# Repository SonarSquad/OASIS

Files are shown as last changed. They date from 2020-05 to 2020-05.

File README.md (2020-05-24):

# OASIS
Contains the complete code, circuit schematics and designs for the OASIS prototype system.
The full OASIS - A low-cost modular echosounder thesis report should also be red for a better understanding if further development of the system are to be investigated.  

**CONTENT: folder and content**
- LNA_Rev3: PCB design files for the LNA board (ALTIUM).
- Oasis_ADC_PCB: PCB design files and gerbers for the ADC board (KICAD).
- Oasis_MCU_bridge_PCB: PCB design files and gerbers for MCU board (KICAD).
- Python code and drivers: Main python script and C- code drivers for the OASIS system
- MCU_ATmega4809: Code for waveform-generation on the ATmega4809. 
- SPI_test_alternative_ADC: Example code for setting up SPI communication on the Raspberry Pi 4 (not used in OASIS prototype).  

**HARDWARE modules:**
- LNA board - Low noise amplifier. (designed and tested)
- MCU board - ATmega4809 Full-bridge module. (designed and tested)
- ADC board - ADS8422 board Analog to Digital converter. (designed and tested)
- Raspberry pi 4 model B (4GB RAM). (bought and tested)

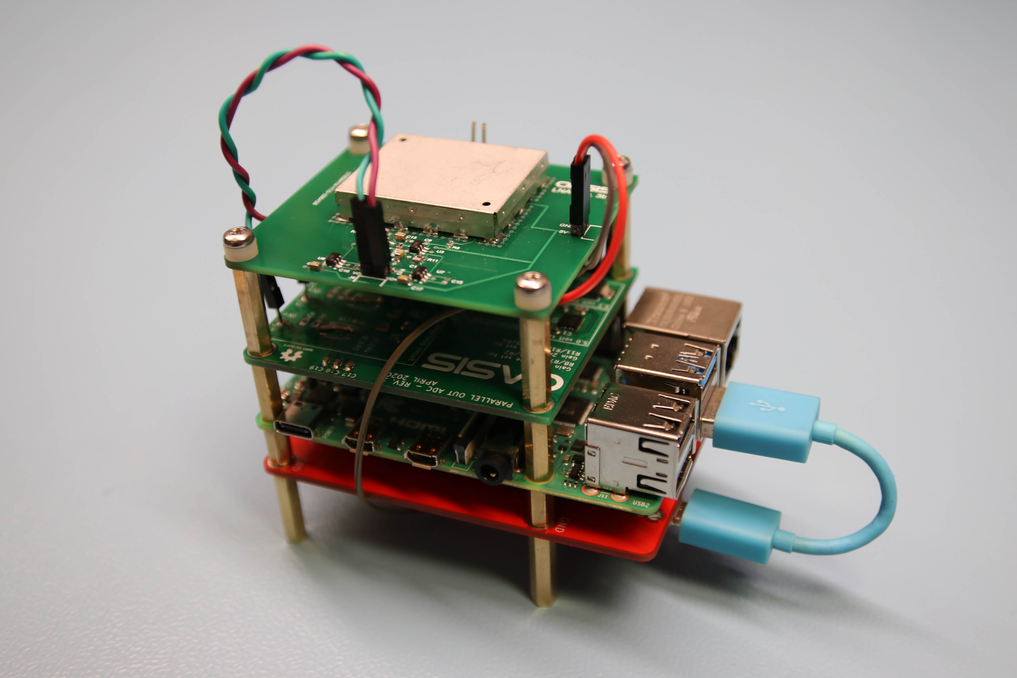
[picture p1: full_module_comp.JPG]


**OASIS Prototype achievements:** 
1. System startup, Transmit a pulse at preset frequency (200kHz).
    - Pulse generaton is done on sepparate microcontroller (MCU).
    
2. Amplify returning echo with LNA.  
    
3. Sample returning echo, (switch not developed yet - two transducers used while testing, one for transmit and one for receive). 
    - Receive and sample incomming returning echo. Sampling @ 1.7 Msps.  

4. Plotting and light processing of received signal.
    - Plot: FFT. 
    - Plot: Time vs. voltage. 
    
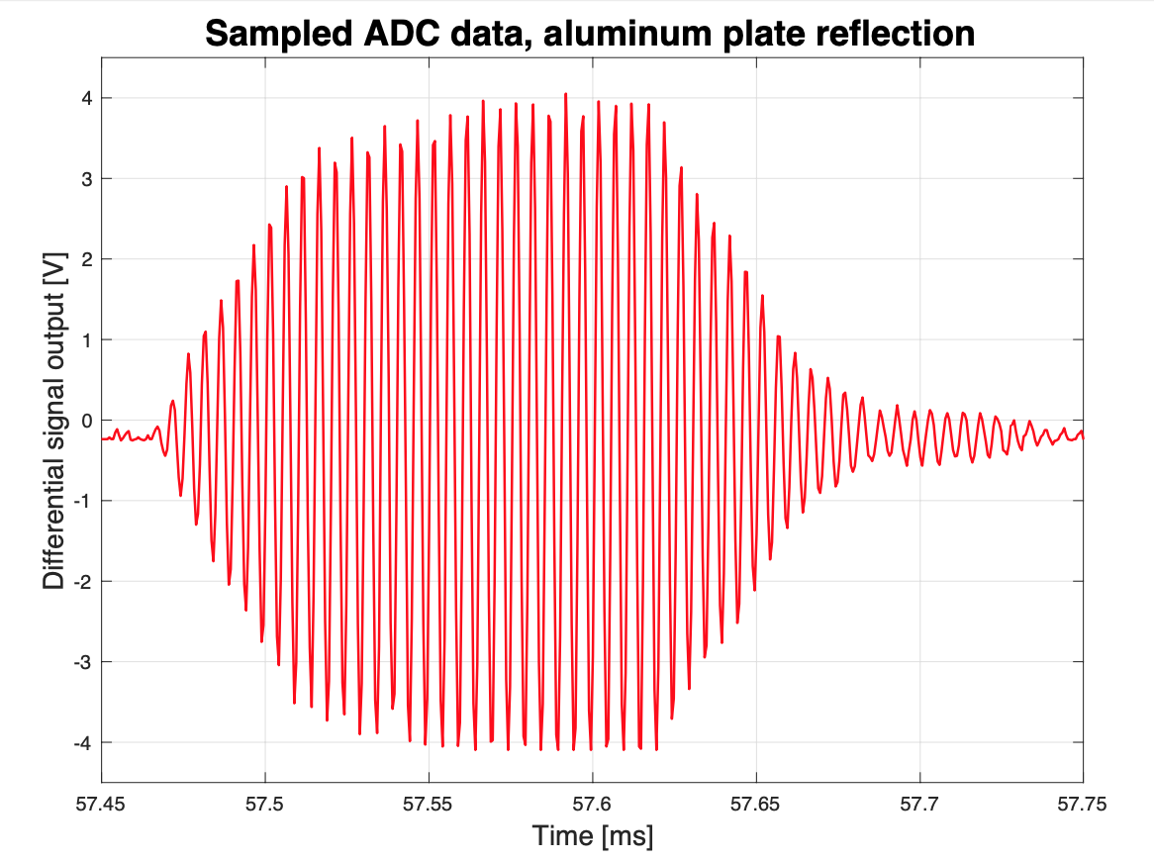
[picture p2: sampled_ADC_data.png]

________________________________________________________________________________________________________
**CONTACT:** 
- Martin Ericsson - tlf: 92649342, email: martincse94@gmail.com 
- Tor K. Gjerde - tlf: 46934462, email: torgjerde.nor@gmail.com
- Torbjørn Willson - tlf: 46810798, email: torbjorw@ntnu.no
- Einar Avdem - tlf: 98813120, email: einarav@stud.ntnu.no

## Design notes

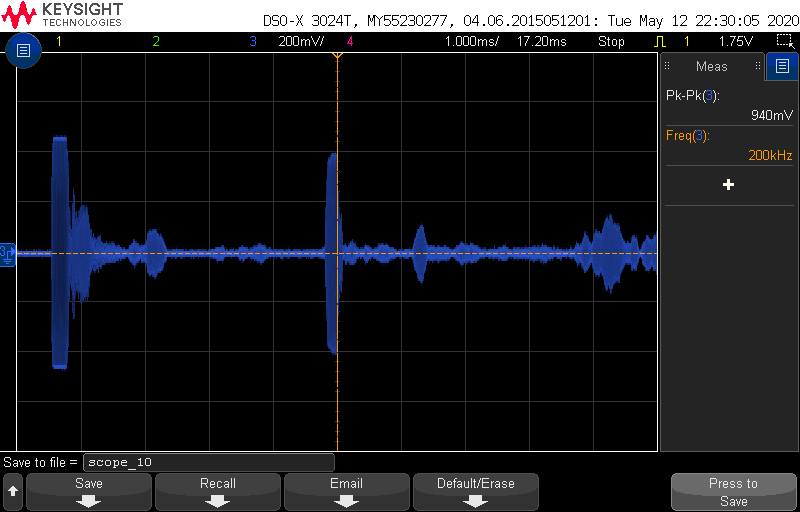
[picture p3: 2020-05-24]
RX_Main_Echo.png

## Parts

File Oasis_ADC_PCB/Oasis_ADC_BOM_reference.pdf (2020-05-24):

/components/comp/@ref /components/comp/datasheet
U1 | ADS8422
C8 | 0.1µF
C7 | 1µF
J5 | Conn_01x01
C9 | 1µF
C12 | 0.1µF
C6 | 0.1µF
C5 | 1µF
C11 | 1µF
C10 | 1µF
J6 | Conn_01x02
U2 | LP38692
U3 | LP2988
C1 | 4.7µF
C2 | 4.7µF
C3 | 1µF
C4 | 1µF
C13 | 10nF
J3 | Conn_01x07
R1 | R
R3 | R
R4 | R
R2 | R
C16 | 1µF
R5 | 12 ohm
C14 | 220pF
J1 | Conn_02x20_Odd_Even
D2 | D_Zener_ALT
U5 | ADA4841-2
J4 | Conn_01x01
R8 | R
R11 | R
R12 | R
R7 | R
C15 | 1µF
U4 | ADA4841-2
R6 | 12 ohm
D1 | D_Zener_ALT
C18 | 4.7µF
C17 | 4.7µF
C19 | 4.7µF

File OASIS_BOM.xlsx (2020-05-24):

Reference PCB: |  | Description: | Value: | Footprint: | Quantity needed: | Price pr. piece (NOK): | Link: | Price total (NOK):
CPU |  | Raspberry pi4 4 GB |  |  | 1 | 641.99 | Click here (https://www.digikey.no/product-detail/no/raspberry-pi/RASPBERRY-PI-4B-4GB/1690-RASPBERRYPI4B-4GB-ND/10258781) | 641.99
CPU |  | Raspberry Power Supply |  |  | 1 | 82.16 | Click here (https://www.digikey.no/product-detail/no/raspberry-pi/RPI-USB-C-POWER-SUPPLY-BLACK-EU/1690-RPIUSB-CPOWERSUPPLYBLACKEU-ND/10258762) | 82.16
 |  |  |  |  |  |  |  | 724.15
Parallel ADC | PCB | JLC PCB |  |  | 1 | 5 |  | 5
Parallel ADC | U1 | ADS8422 16-bit ADC Texas | ADS8422 | 48-TQFP | 1 | 547.05 | Click here (https://www.digikey.no/product-detail/en/texas-instruments/ADS8422IBPFBT/296-21325-1-ND/1258258) | 547.05
Parallel ADC | J1 | Pin-header connectors - 2x20 pins | 1979 Adafruit | NA | 1 | 31.00 | Click here (https://www.digikey.no/product-detail/en/adafruit-industries-llc/1979/1528-1783-ND/6238003) | 31
Parallel ADC | D1, D2 | Zener diode for ADC protection | MM3Z3V3T1G | SOD-232 | 2 | 1.47 | Click here (https://www.digikey.no/product-detail/no/on-semiconductor/MM3Z3V3T1G/MM3Z3V3T1GOSCT-ND/2623467) | 2.94
Parallel ADC | U2 | LP38692MP-3.3 - 3.3 volt supply | LDO | SOT-223-5 | 1 | 16.25 | Click here (https://www.digikey.com/product-detail/en/texas-instruments/LP38692MP-3-3-NOPB/LP38692MP-3-3-NOPBTR-ND/723328) | 16.25
Parallel ADC | U3 | LP2989ILDX-5.0 - 5.0 volt supply | LDO | 8-WSON | 1 | 15.24 | Click here (https://www.digikey.no/product-detail/no/texas-instruments/LP38693MP-3-3-NOPB/LP38693MP-3-3-NOPBCT-ND/755153) | 15.24
Parallel ADC | C6, C8, C12 | Capacitor - E12 series | 100nF capacitor | 0603 | 3 | 1.5 |  | 4.5
Parallel ADC | C3-C5, C7, C9-C11 | Capacitor - E12 series | 1µF capacitor | 0603 | 7 | 1.5 |  | 10.5
Parallel ADC | C1, C2, C17, C18, C19 | Capacitor | 4.7µF | 0603 | 5 | 2.00 |  | 10
Parallel ADC | C13 | Capacitor - E12 series | 10nF | 0603 | 1 | 1.5 |  | 1.5
Parallel ADC | C14 | Capacitor - E12 series | Unused | 0603 | 0 | 0 |  | 0
Parallel ADC | R5, R6 | Resistor - E12 series | 12 ohm | 0805 | 2 | 1.5 |  | 3
Parallel ADC | R1-R4,R7,R8,R11,R12 | Resistor - E12 series | Unused | 0805 | 8 | 0 |  | 0
 |  |  |  |  |  |  |  | 646.98
LNA REV. 3 | PCB | JLC PCB |  |  | 1 | 5 |  | 5
LNA REV. 3 | U1, U2, U3, U4, U7, U8 | Op-amp | ADA4841 | SOT23-6 | 6 | 52.86 | Click here (https://www.digikey.no/product-detail/no/analog-devices-inc/ADA4841-1YRJZ-R2/ADA4841-1YRJZ-R2DKR-ND/4910681) | 317.16
LNA REV. 3 | SHIELD | RF-sheild | SMS-457F | N/A | 1 | 20.99 | Click here (https://www.digikey.no/product-detail/en/SMS-457F/1798-1227-6-ND/7203636/?itemSeq=321058078) | 20.99
LNA REV. 3 | SHIELD | RF-shield Lid | SMS-457C | N/A | 1 | 6.44 | Click here (https://www.digikey.no/product-detail/en/leader-tech-inc/SMS-457C/1798-1226-ND/7203484) | 6.44
LNA REV. 3 | D5, D6 | TVS-diodes | SMBJ3V3-E3/52 | Self-defined | 2 |  | Click here (https://www.digikey.no/product-detail/en/SMBJ3V3-E3-52/SMBJ3V3-E3-52GICT-ND/1147834?) | 0
LNA REV. 3 | D1, D2, D3, D4 | Saturation diodes | S1M-13-F | Self-defined |  |  | Click here (https://www.digikey.no/product-detail/no/diodes-incorporated/S1M-13-F/S1M-FDIDKR-ND/1811188) | 0
LNA REV. 3 | C1,C2 | Capacitor - E12 series | 100pF | 0603 | 2 | 1.5 |  | 3
LNA REV. 3 | C3,C4,C13,C14,C17,C18 | Capacitor | 10uF | 0805 | 6 | 1.69 |  | 10.14
LNA REV. 3 | C5,C6,C11,C12 | Capacitor - E12 series | 22pF | 0603 | 4 | 1.5 |  | 6
LNA REV. 3 | C7,C8,C9,C10,C15,C16 | Capacitor - E12 series | unused | 0603 | 6 | 0 |  | 0
LNA REV. 3 | R1,R3 | Resistor - E12 series | 330kΩ | 0603 | 2 | 1.5 |  | 3
LNA REV. 3 | R2,R4 | Resistor - E12 series | 220kΩ | 0603 | 2 | 1.5 |  | 3
LNA REV. 3 | R5,R6,R11,R12 | Resistor - E12 series | 4.7kΩ | 0603 | 4 | 1.5 |  | 6
LNA REV. 3 | R7 | Resistor - E12 series | 560Ω | 0603 | 1 | 1.5 |  | 1.5
LNA REV. 3 | R10 | Resistor - E12 series | 6.7kΩ | 0603 | 1 | 1.5 |  | 1.5
LNA REV. 3 | R13,R14 | Resistor - E12 series | 330kΩ | 0603 | 2 | 1.5 |  | 3
 |  |  |  |  |  |  |  | 386.73
MCU - H-BRIDGE | PCB |  |  |  | 1 | 5 |  | 5
MCU - H-BRIDGE | PCB | Atmega4809 curiosity nano | ATmega4809 | Self-defined | 1 | 140.76 | Click here (https://www.digikey.no/product-detail/no/linear-technology-analog-devices/LTC1693-2IS8-PBF/LTC1693-2IS8-PBF-ND/890468) | 140.76
MCU - H-BRIDGE | PCB | MOSFET Driver Low & High side | LTC1693-2 | SOIC8 | 2 | 43.48 | Click here | 86.96
MCU - H-BRIDGE | PCB | NMOS | PMV164ENEAR | SOT23 | 4 | 2.5652 | Click here (https://www.digikey.no/product-detail/no/nexperia-usa-inc/PMV164ENEAR/1727-8650-1-ND/10440319) | 10.2608
MCU - H-BRIDGE | PCB | Capacitor - E12 series | 1nF | 0603 | 2 | 1.5 |  | 3
MCU - H-BRIDGE | PCB | LP38692MP - 3.3 volt supply | LP38692MP-3.3 | SOT-223-5 | 1 | 16.25 | Click here (https://www.digikey.no/product-detail/no/texas-instruments/LP38693MP-3-3-NOPB/LP38693MP-3-3-NOPBCT-ND/755153) | 16.25
 |  |  |  |  |  |  |  | 262.2308
 |  |  |  |  |  |  |  | 2020.0908

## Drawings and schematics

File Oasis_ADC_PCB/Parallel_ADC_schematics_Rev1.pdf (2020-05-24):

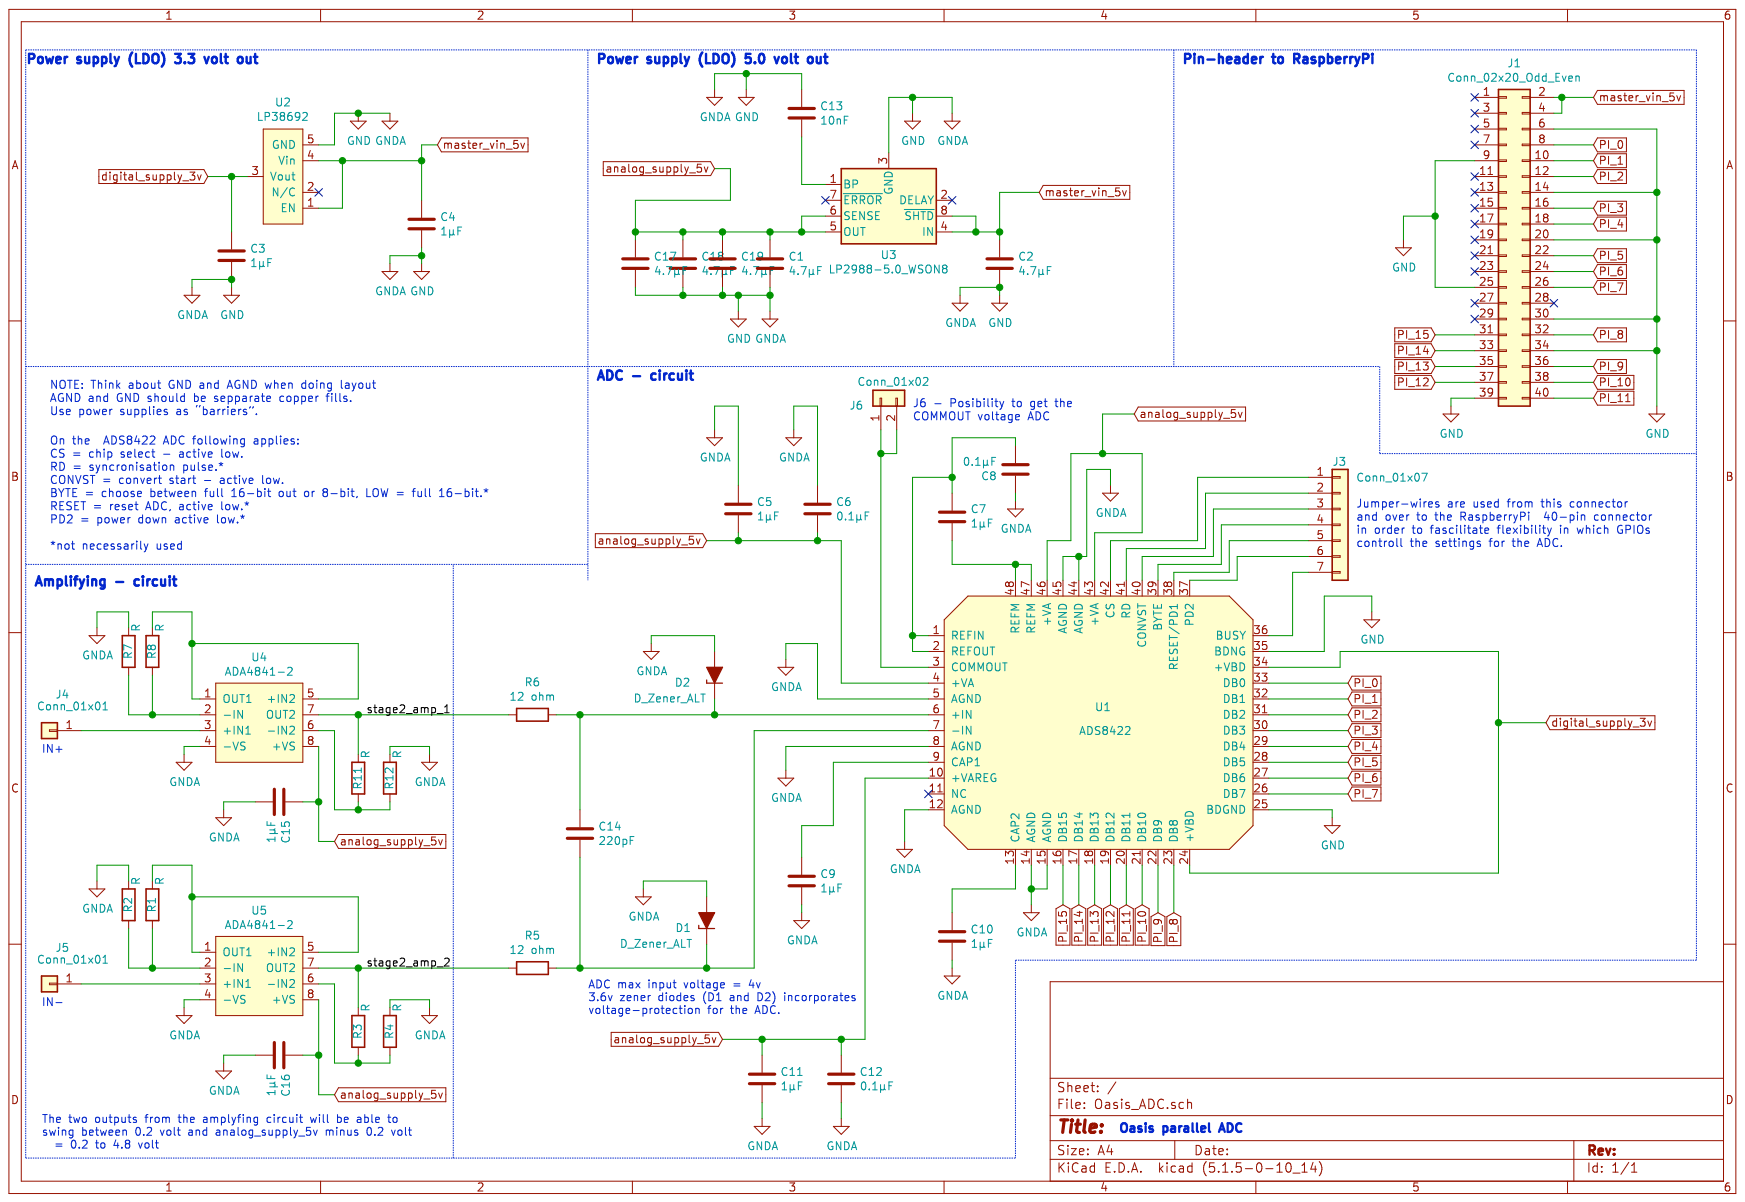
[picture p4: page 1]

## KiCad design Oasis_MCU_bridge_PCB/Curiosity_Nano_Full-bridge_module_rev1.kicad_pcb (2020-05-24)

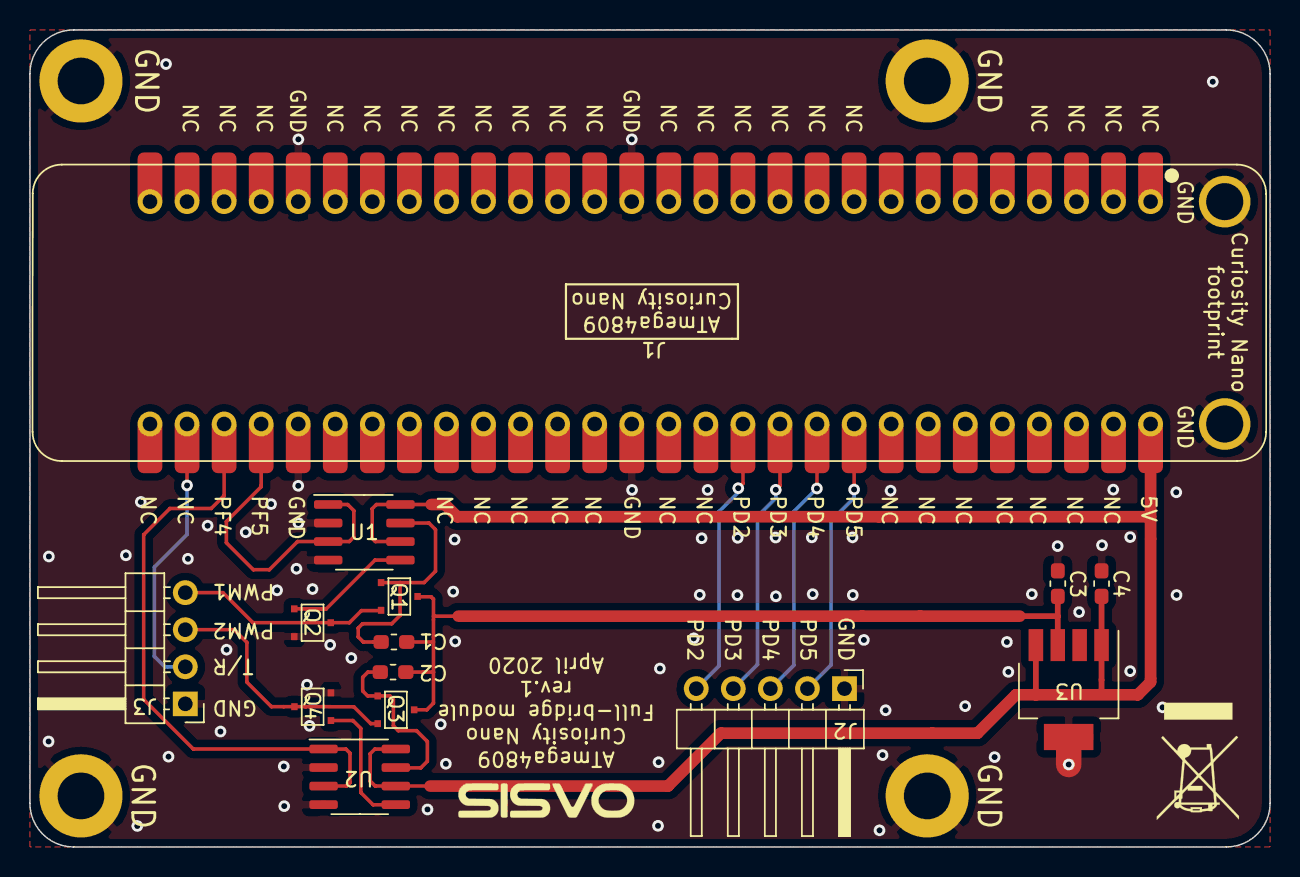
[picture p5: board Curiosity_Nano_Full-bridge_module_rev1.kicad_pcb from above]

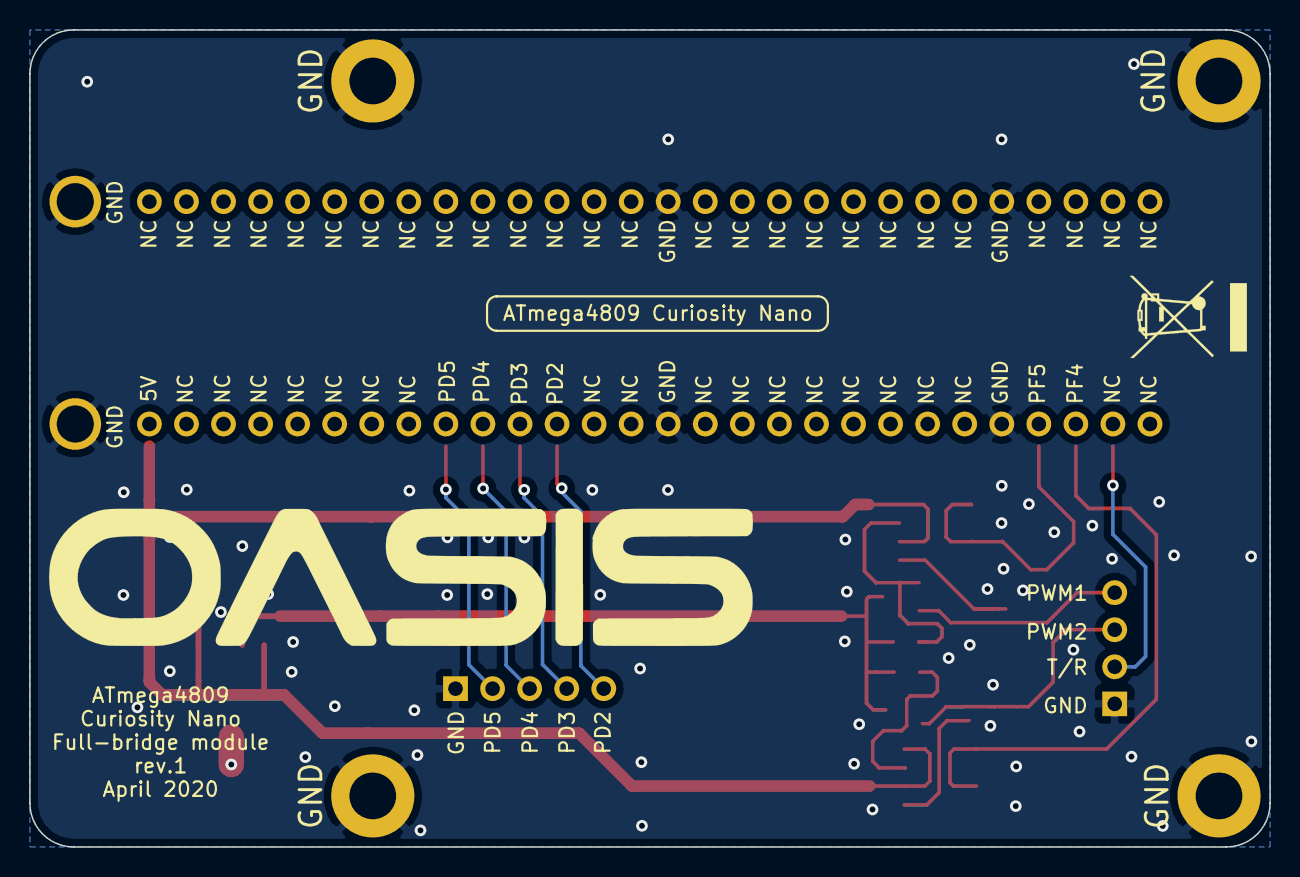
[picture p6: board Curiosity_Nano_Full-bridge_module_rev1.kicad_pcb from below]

Board: 2 copper layers, 85.0 x 56.0 mm, 18 parts (4 on the bottom side), 16 nets.

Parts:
C1, C2: 560pF; C_0603_1608Metric_Pad1.05x0.95mm_HandSolder
C3, C4: 1µF; C_0603_1608Metric_Pad1.05x0.95mm_HandSolder
GND: MountingHole_3.2mm_M3_ISO7380_Pad
GND#2, GND#3, GND#4: MountingHole_3.2mm_M3_ISO7380_Pad
J1: CuNanConn; ATmega4809_Curisoity_Nano
J2: Conn_01x05; PinHeader_1x05_P2.54mm_Horizontal
J3: Conn_01x04; PinHeader_1x04_P2.54mm_Horizontal
Q1, Q2, Q3, Q4: PMV164ENEA; BSS123
U1, U2: LTC1693-2; SOIC-8_3.9x4.9mm_P1.27mm
U3: LP38693MP; SOT-223-5

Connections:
+3V3: C1.1, C2.1, C3.2, Q1.3, Q3.3, U3.3
+5V: C4.1, J1.29, U1.6, U1.8, U2.6, U2.8, U3.1, U3.4
Earth: C3.1, C4.2, GND.1, GND#2.1, GND#3.1, GND#4.1, J1.15, J1.24, J1.43, J1.52, J1.57, J2.1, J3.1, Q2.2, Q4.2, U1.2, U1.4, U2.2, U2.4, U3.5
unnamed: C1.2, Q1.1, U1.7
unnamed: C2.2, Q3.1, U2.7
unnamed: Q2.1, U1.5
unnamed: Q4.1, U2.5
PD2: J1.40, J2.5
PD3: J1.39, J2.4
PD4: J1.38, J2.3
PD5: J1.37, J2.2
PWM1_IN: J1.53, U1.1, U1.3
PWM1_OUT: J3.4, Q1.2, Q2.3
PWM2_IN: J1.54, U2.1, U2.3
PWM2_OUT: J3.3, Q3.2, Q4.3
T-R: J1.55, J3.2

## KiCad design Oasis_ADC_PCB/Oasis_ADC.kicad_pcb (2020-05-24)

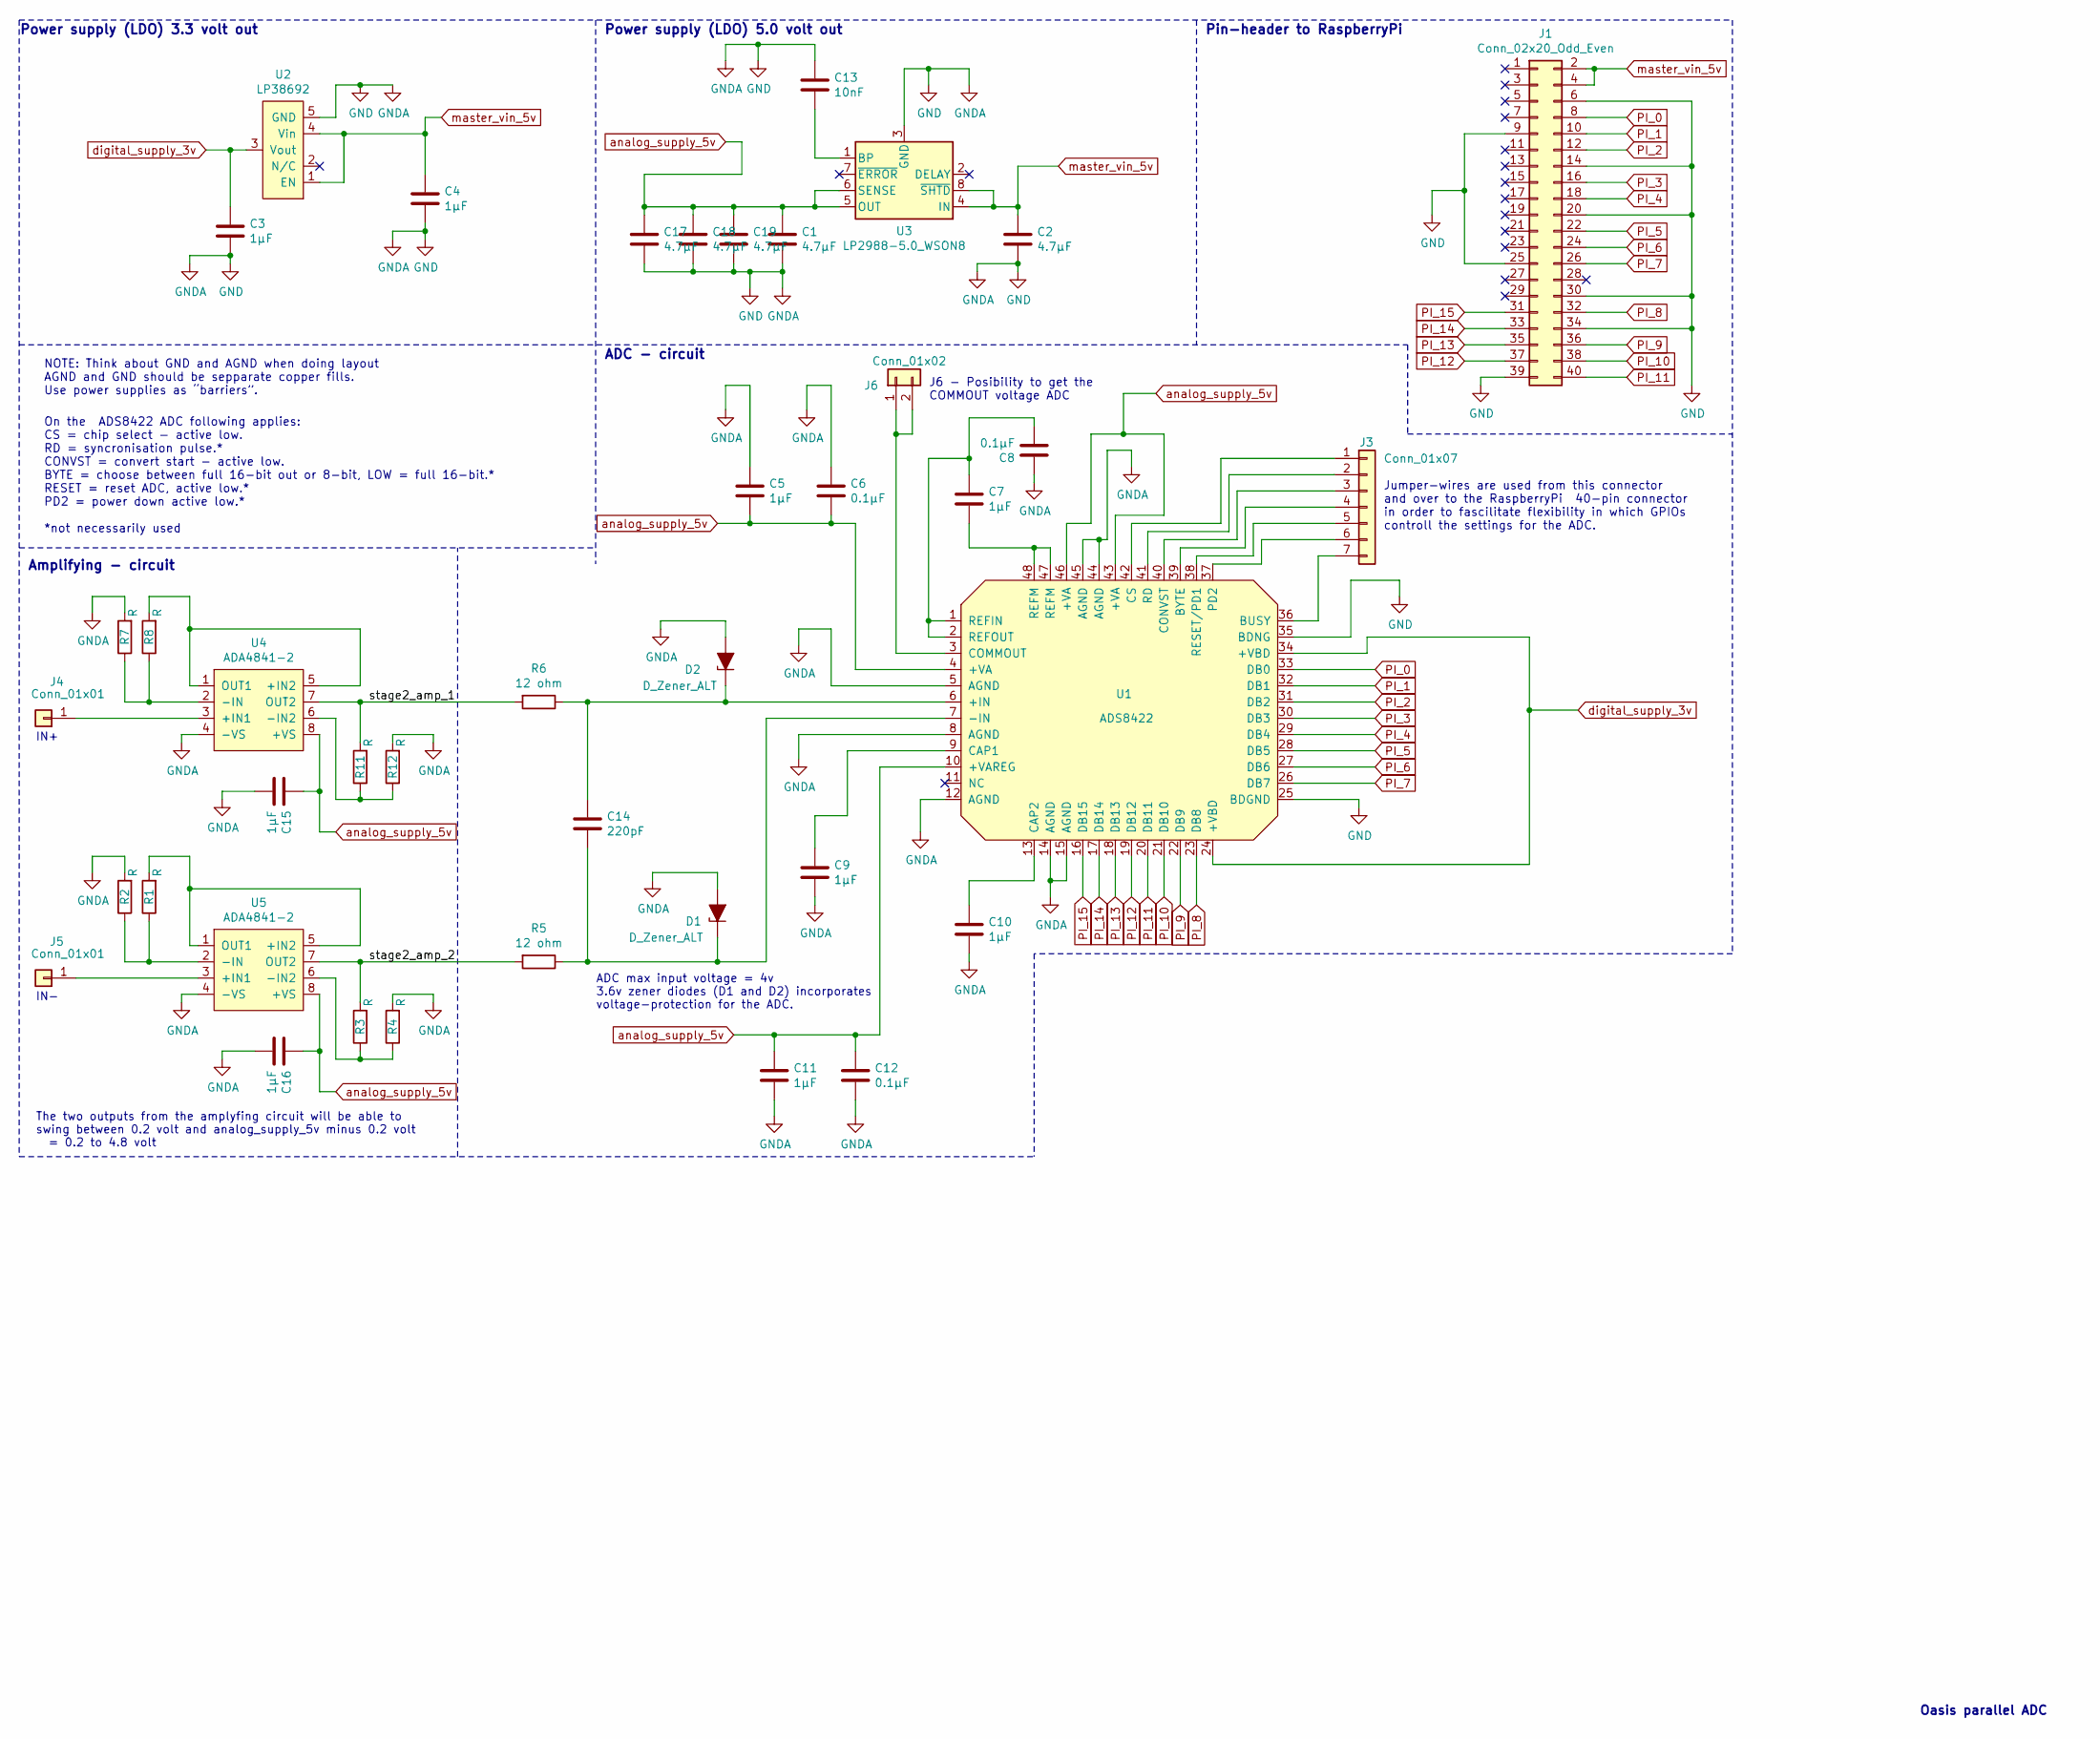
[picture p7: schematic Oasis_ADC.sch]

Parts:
C1, C2, C19: 4.7µF; C_0603_1608Metric_Pad1.05x0.95mm_HandSolder
C3, C4, C5, C7, C9, C10, C11, C15, C16: 1µF; C_0603_1608Metric_Pad1.05x0.95mm_HandSolder
C6, C8, C12: 0.1µF; C_0603_1608Metric_Pad1.05x0.95mm_HandSolder
C13: 10nF; C_0603_1608Metric_Pad1.05x0.95mm_HandSolder
C14: 220pF; C_0603_1608Metric_Pad1.05x0.95mm_HandSolder
C17, C18: 4.7µF; C_0805_2012Metric
D1, D2: D_Zener_ALT; D_SOD-323
J1: Conn_02x20_Odd_Even; PinHeader_2x20_P2.54mm_Vertical
J3: Conn_01x07; PinHeader_1x07_P2.54mm_Vertical
J4, J5: Conn_01x01; PinHeader_1x01_P2.54mm_Vertical
J6: Conn_01x02; PinHeader_1x02_P2.54mm_Vertical
R1, R2, R3, R4, R7, R8, R11, R12: R; R_0805_2012Metric
R5, R6: 12 ohm; R_0805_2012Metric
U1: ADS8422
U2: LP38692; SOT-223-5
U3: LP2988-5.0_WSON8; WSON-8_4x4mm_P0.8mm
U4, U5: ADA4841-2; SOIC-8_3.9x4.9mm_P1.27mm

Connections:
/stage2_amp_1: R6.2, R11.2, U4.7 (OUT2)
/stage2_amp_2: R3.2, R5.2, U5.7 (OUT2)
GND: C1.2, C2.2, C3.2, C4.2, C5.1, C6.1, C8.1, C9.2, C10.2, C11.2, C12.2, C13.1, C15.2, C16.2, C17.2, C18.2, C19.2, D1.2 (A), D2.2 (A), J1.6, J1.9, J1.14, J1.20, J1.25, J1.30, J1.34, J1.39, R2.2, R4.2, R7.2, R12.2, U1.5 (AGND), U1.8 (AGND), U1.12 (AGND), U1.14 (AGND), U1.15 (AGND), U1.25 (BDGND), U1.35 (BDNG), U1.44 (AGND), U1.45 (AGND), U2.5 (GND), U3.3 (GND), U3.9 (GND), U4.4 (-VS), U5.4 (-VS)
unnamed: C7.1, U1.47 (REFM), U1.48 (REFM)
unnamed: C7.2, C8.2, U1.1 (REFIN), U1.2 (REFOUT)
unnamed: C9.1, U1.9 (CAP1)
unnamed: C10.1, U1.13 (CAP2)
unnamed: C13.2, U3.1 (BP)
unnamed: C14.1, D2.1 (K), R6.1, U1.6 (+IN)
unnamed: C14.2, D1.1 (K), R5.1, U1.7 (-IN)
unnamed: J3.1, U1.42 (CS)
unnamed: J3.2, U1.41 (RD)
unnamed: J3.3, U1.40 (CONVST)
unnamed: J3.4, U1.39 (BYTE)
unnamed: J3.5, U1.38 (RESET/PD1)
unnamed: J3.6, U1.37 (PD2)
unnamed: J3.7, U1.36 (BUSY)
unnamed: J4.1, U4.3 (+IN1)
unnamed: J5.1, U5.3 (+IN1)
unnamed: J6.1, J6.2, U1.3 (COMMOUT)
unnamed: R1.1, R2.1, U5.2 (-IN)
unnamed: R1.2, U5.1 (OUT1), U5.5 (+IN2)
unnamed: R3.1, R4.1, U5.6 (-IN2)
unnamed: R7.1, R8.1, U4.2 (-IN)
unnamed: R8.2, U4.1 (OUT1), U4.5 (+IN2)
unnamed: R11.1, R12.1, U4.6 (-IN2)
PI_0: J1.8, U1.33 (DB0)
PI_1: J1.10, U1.32 (DB1)
PI_2: J1.12, U1.31 (DB2)
PI_3: J1.16, U1.30 (DB3)
PI_4: J1.18, U1.29 (DB4)
PI_5: J1.22, U1.28 (DB5)
PI_6: J1.24, U1.27 (DB6)
PI_7: J1.26, U1.26 (DB7)
PI_8: J1.32, U1.23 (DB8)
PI_9: J1.36, U1.22 (DB9)
PI_10: J1.38, U1.21 (DB10)
PI_11: J1.40, U1.20 (DB11)
PI_12: J1.37, U1.19 (DB12)
PI_13: J1.35, U1.18 (DB13)
PI_14: J1.33, U1.17 (DB14)
PI_15: J1.31, U1.16 (DB15)
analog_supply_5v: C1.1, C5.2, C6.2, C11.1, C12.1, C15.1, C16.1, C17.1, C18.1, C19.1, U1.4 (+VA), U1.10 (+VAREG), U1.43 (+VA), U1.46 (+VA), U3.5 (OUT), U3.6 (SENSE), U4.8 (+VS), U5.8 (+VS)
digital_supply_3v: C3.1, U1.24 (+VBD), U1.34 (+VBD), U2.3 (Vout)
master_vin_5v: C2.1, C4.1, J1.2, J1.4, U2.1 (EN), U2.4 (Vin), U3.4 (IN), U3.8 (~SHTD)

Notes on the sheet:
On the ADS8422 ADC following applies: CS = chip select - active low. RD = syncronisation pulse.* CONVST = convert start - active low. BYTE = choose between full 16-bit out or 8-bit, LOW = full 16-bit.* RESET = reset ADC, active low.* PD2 = power down active low.* *not necessarily used
NOTE: Think about GND and AGND when doing layout AGND and GND should be sepparate copper fills. Use power supplies as “barriers”.
Power supply (LDO) 3.3 volt out
Pin-header to RaspberryPi
Power supply (LDO) 5.0 volt out
Amplifying - circuit
ADC - circuit
Jumper-wires are used from this connector and over to the RaspberryPi 40-pin connector in order to fascilitate flexibility in which GPIOs controll the settings for the ADC.
J6 - Posibility to get the COMMOUT voltage ADC
Oasis parallel ADC
The two outputs from the amplyfing circuit will be able to swing between 0.2 volt and analog_supply_5v minus 0.2 volt = 0.2 to 4.8 volt
ADC max input voltage = 4v 3.6v zener diodes (D1 and D2) incorporates voltage-protection for the ADC.
IN+
IN-

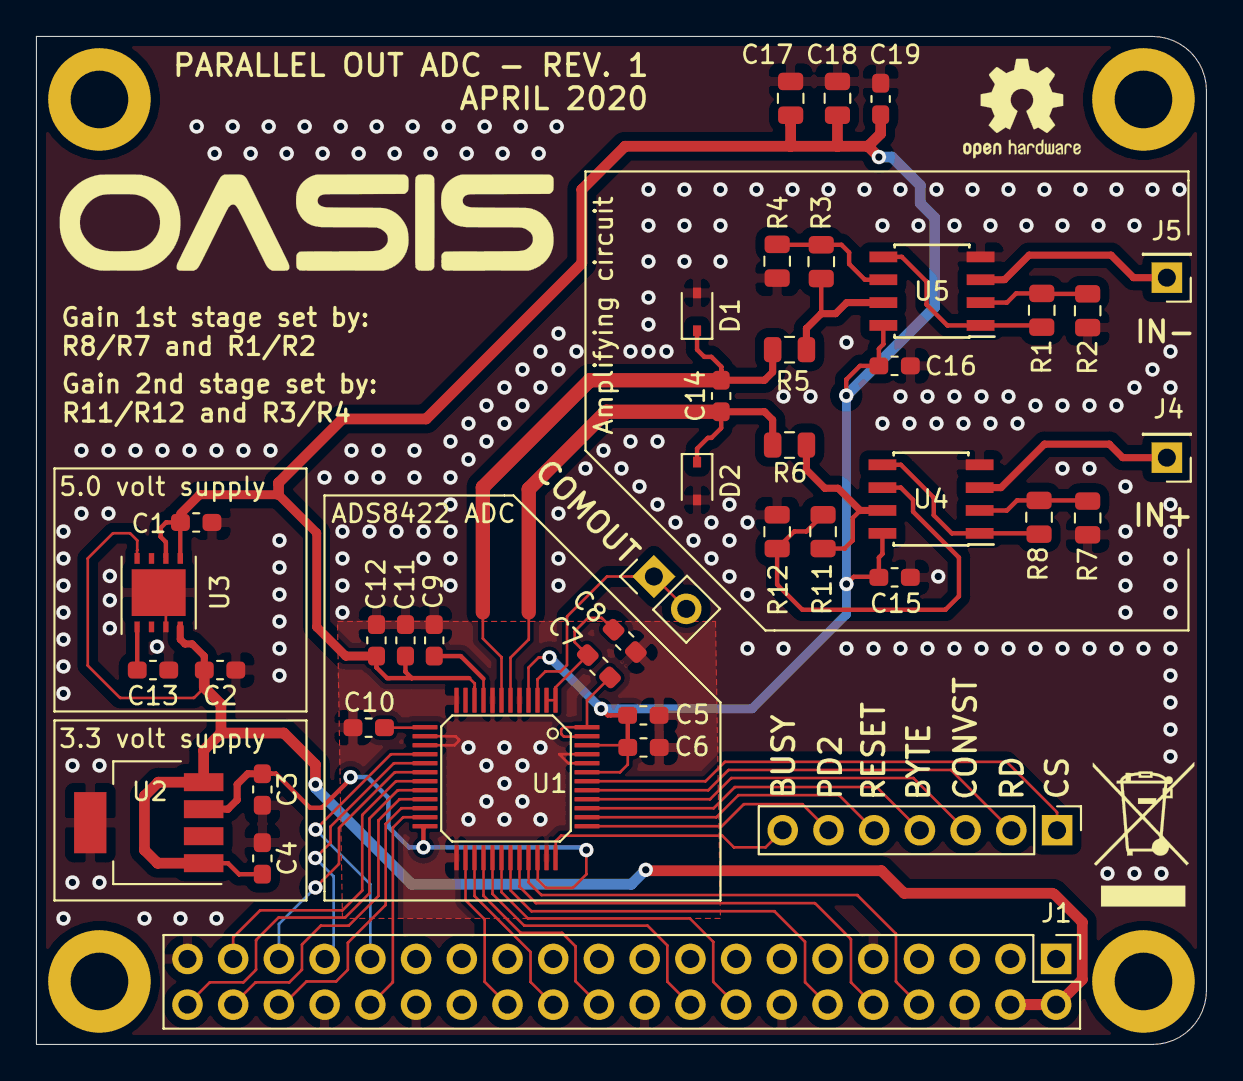
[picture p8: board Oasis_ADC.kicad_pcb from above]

Board: 2 copper layers, 65.0 x 56.0 mm, 41 parts (0 on the bottom side), 45 nets.

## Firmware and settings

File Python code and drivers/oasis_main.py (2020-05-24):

# ---------- Imports for Plotting ------------------------------------
import matplotlib.pyplot as plt
from matplotlib.pyplot import ion, show

# ---------- Other imports -------------------------------------------
import math
import time
import RPi.GPIO as GPIO
from subprocess import Popen, PIPE
from scipy.fft import fft


# --------------------- FUNCTIONS ------------------------------------------------------------------------------------------------------

def get_ADC_data(): 
    # This function initiates a process and 
    # returns a list with 1.7 million voltage readings taken at 1.7MHz sampling frequency.
    # The sampling frequency and number of samples taken can adjusted in the C-driver (max = 1.7MHz @ 2M samples)
    # The compiled and executable C-code needs to be in the same directory as this python file.  

    Vref = 4.096 # Reference voltage used in the ADC. 4.096 for internal reference ADS8422 

    # Start a subprocess: call the C code and let it run to do a parallel ADC read. 
    c_process = Popen("./oasis_read_ADC_parallel", stdin = PIPE, stdout = PIPE)
    OUTS, errs = c_process.communicate()

    """
    -----------------------------------------------------------------------------------------------------------------------------------------
    Now the variable "OUTS" (bytes object) contains a list with the states of the GPIO register after each ADC sample.
    - Each entry in the list is an integer. 
    - Each integer represents a 32-bit register read.
    -----------------------------------------------------------------------------------------------------------------------------------------
    # The rest of this function converts the list of integers received from the C code into a list with voltages. 
     ----------------------------------------------------------------------------------------------------------------------------------------
    2. Convert integers to 32-bit bit-string.
    3. Manipulate string in order to extract the bits representing the GPIOs physically connected to the data lines of ADC.
    4. Sort the manipulated bits so that they have the right place in a 16-bit string. 
    5. Convert the 16-bit string to voltage reading - remember 16-bit value is two's complement.   
    -----------------------------------------------------------------------------------------------------------------------------------------
    """    

    data = OUTS.decode('UTF-8')               # Decode outs from byte-object and make a python string
    data_list_string = data.split(',')        # Split the string at comma and put all entries into a new python list 
    number_of_samples = len(data_list_string) # Get the total number of samples 
    
    data_list_int = list(map(int, data_list_string)) # Convert string-entries to integers 

    bit32_list_string = [0]*number_of_samples   # Preallocating list
    for i in range(0,number_of_samples):        # Convert integers from data_list_int to bit-string of 32 bit length. 
        bit32_list_string[i] = ('{0:032b}'.format(data_list_int[i]))  

    bit16_list_string = [0]*number_of_samples   # Preallocating list 
    for i in range(0,number_of_samples):        # Extract bit position for the 16 GPIOs of interest from 32-bit bit-string. 
        bits = bit32_list_string[i]      
        #                    ADC-bit = RaspberryPi            index = (31 - GPIO)
        bit0  = bits[17]   # bit 0 =  GPIO 14       bit32_list_string  index 17
        bit1  = bits[16]   # bit 1 =  GPIO 15       bit32_list_string  index 16 
        bit2  = bits[13]   # bit 2 =  GPIO 18       bit32_list_string  index 13
        bit3  = bits[8]    # bit 3 =  GPIO 23       bit32_list_string  index 8 
        bit4  = bits[7]    # bit 4 =  GPIO 24       bit32_list_string  index 7 
        bit5  = bits[6]    # bit 5 =  GPIO 25       bit32_list_string  index 6 
        bit6  = bits[23]   # bit 6 =  GPIO 8        bit32_list_string  index 23 
        bit7  = bits[24]   # bit 7 =  GPIO 7        bit32_list_string  index 24 
        bit8  = bits[19]   # bit 8 =  GPIO 12       bit32_list_string  index 19 
        bit9  = bits[15]   # bit 9 =  GPIO 16       bit32_list_string  index 15 
        bit10 = bits[11]   # bit 10 = GPIO 20       bit32_list_string  index 11 
        bit11 = bits[10]   # bit 11 = GPIO 21       bit32_list_string  index 10 
        bit12 = bits[5]    # bit 12 = GPIO 26       bit32_list_string  index 5 
        bit13 = bits[12]   # bit 13 = GPIO 19       bit32_list_string  index 12 
        bit14 = bits[18]   # bit 14 = GPIO 13       bit32_list_string  index 18 
        bit15 = bits[25]   # bit 15 = GPIO 6        bit32_list_string  index 25 

        # Format 16-bit string: bit16_list_string[0] = MSB, bit16_list_string[15] = LSB
	    # Two's complement representation 
        bit16_list_string[i] = (bit15 + bit14 + bit13 + bit12 + bit11 + bit10 + bit9 + bit8 + bit7 + bit6 + bit5 + bit4 + bit3 + bit2 + bit1 + bit0)
    


    bit16_list_int = [0]*number_of_samples
    for i in range(0, number_of_samples):                   # Convert bit string back to integer 
        bit16_list_int[i] = int(bit16_list_string[i],2)     
    
        if bit16_list_int[i] > 32767:                       # Convert from two's complement   2**15-1 = 32767
            bit16_list_int[i] = -65536 + bit16_list_int[i]

    ADC_list_voltage = [0]*number_of_samples                # Convert ADC bit-data to voltage reading
    for i in range(0, number_of_samples):
        ADC_list_voltage[i] = (Vref) * (bit16_list_int[i] / (2**15))
    
    # The list: ADC_list_voltage now contains all samples presented as voltage.   
    return ADC_list_voltage

# --------------------------------- END FUNCTION ------------------------------------------------------------------------------------------

#--------------------------------------SETUP ----------------------------------------------------------------------------------------------
# The ADS8422 Driver needs to be in the same folder as this oasis_main.py script. 
# Before running the main code the C driver needs to be compiled. 
# In order to compile the C driver run the following in terminal:
# gcc oasis_ADS8422_ADC_parallel.c.c -o  oasis_ADS8422_ADC_parallel.c

# Following connections are made between the ADS8422 ADC Board and RaspberryPi: 
# CONVST = GPIO 4
# BUSY = GPIO 3
# RD = GPIO 17 
# CS = connect to LOW        (GND)
# BYTE = connect to LOW      (GND)
# RESET = connect to HIGH   (3.3v)
# PD2 = connect to HIGH     (3.3v) 
# Connect GPIO 1 and GPIO 0 to the MCU 

sampling_frequency = 1700000

GPIO.setmode(GPIO.BCM)
GPIO.setup(1, GPIO.OUT) # GPIO 1 used for communication Raspberry --> MCU 
GPIO.setup(0, GPIO.IN)  # GPIO 0 used for communication MCU --> Raspberry
RUN = True 

# ----------------------------------- MAIN LOOP -------------------------------------------------------------------------------------------
while RUN == True:
	
    GPIO.output(1,1) # Pulse pin 1 to in order to trigger MCU to start chirping. 
    GPIO.output(1,0) 
	
    while GPIO.input(0) == HIGH: 
        # Wait for MCU to pull it's interface wire low. LOW signals indicates chirping done.  
 
    voltage_list = get_ADC_data() # start sampling the returning echo signal
    number_of_samples = len(voltage_list)

    command_FFT = input("Plot FFT?  Y/N: ") # User input through terminal 
    if command_FFT == "Y": # Set up and plot FFT: 
        N = number_of_samples
        
        x_vect = [0] * N    # Set up a frequency vector for the x-axis of plot       
        for i in range(0, N):
	        x_vect[i] = (i * (sampling_frequency/N))/1000   # Divide by 1000 to get KHz along X axis  
        

        fft_data = fft(voltage_list, N) # Take the FFT of the original voltage data
        FFT_abs = abs(fft_data) # Absolute value 
        FFT_scaled = ((FFT_abs / N) * 2)  # Scaled and multiplied by 2 - only one mirrored part valid in FFT.
        ion() 
        plt.figure(1)
        plt.style.use('seaborn-whitegrid')
        plt.plot(x_vect, FFT_scaled, color ='red', linewidth=1)
        plt.title('FFT of sampled signal')
        plt.xlabel('Frequency KHz')
        plt.ylabel('Magnitude')
        plt.tight_layout()
        plt.show() 
        
    
    command_PLOT = input("Plot voltage vs. time?  Y/N: ") # User input through terminal 
    if command_PLOT == "Y":                               # Plot data                  
        samples = [0]*number_of_samples 
        for i in range(0, number_of_samples): # set up sample number vector for x-axis 
            samples[i] = i
        ion()
        plt.figure(2)
        plt.style.use('seaborn-whitegrid')
        plt.plot(samples, voltage_list, color ='red', linewidth=1)
        plt.title('Plotting of ADC voltage data')
        plt.xlabel('Sample nbr.')
        plt.ylabel('voltage difference between inputs')
        plt.tight_layout()
        plt.show()


    command_SAVE = input("Save voltage samples to .txt file? Y/N: ") # User input through terminal 
    if command_SAVE == "Y":                                          # Save sampled data to a .txt file 
        file_name_input_str = input("Insert filename: ")
        file_name_str = file_name_input_str + ".txt"
        
        file_object = open(file_name_str, "w+")
        file_object.write(str(voltage_list))
        print("SUCCESS! Sampling-session saved as:", file_name_str)

    RUN = False 

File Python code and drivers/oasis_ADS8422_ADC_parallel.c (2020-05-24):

// OASIS ADC driver for ADS8422 Texas Instrument, parallel interface. 

#include "RPI4.h" 
#include <stdio.h>
#include <stdlib.h>
#include <unistd.h>



//---------------------- FUNCTIONS ---------------------------------------------------
struct bcm2835_peripheral gpio = {GPIO_BASE};


// Exposes the physical address defined in the passed structure using mmap on /dev/mem
int map_peripheral(struct bcm2835_peripheral *p)
{
   // Open /dev/mem
   if ((p->mem_fd = open("/dev/mem", O_RDWR|O_SYNC) ) < 0) {
      printf("Failed to open /dev/mem, check permissions.\n");
      return -1;
   }

   p->map = mmap(
      NULL,
      BLOCK_SIZE,
      PROT_READ|PROT_WRITE,
      MAP_SHARED,
      p->mem_fd,  // File descriptor to physical memory virtual file '/dev/mem'
      p->addr_p      // Address in physical map that we want this memory block to expose
   );

   if (p->map == MAP_FAILED) {
        perror("mmap");
        return -1;
   }

   p->addr = (volatile unsigned int *)p->map;

   return 0;
}

void unmap_peripheral(struct bcm2835_peripheral *p) {

    munmap(p->map, BLOCK_SIZE);
    close(p->mem_fd);
}

// -------------------------------------- MAIN -------------------------------------------------------
int main()
{
	if(map_peripheral(&gpio) == -1)
	{
		printf(" ERROR! failed to map physical GPIO registers into the virtual memory.\n");
		return -1; 
	}

	/*
   Define GPIOs as input 
   GPIOs used as laid out on the parallel ADC circuit board: ADS8422 -> Raspberry Pi 
   bit 0 =  GPIO 14     32-bit-string index 15
   bit 1 =  GPIO 15     32-bit-string index 16
   bit 2 =  GPIO 18     32-bit-string index 19
   bit 3 =  GPIO 23     32-bit-string index 24
   bit 4 =  GPIO 24     32-bit-string index 25
   bit 5 =  GPIO 25     32-bit-string index 26
   bit 6 =  GPIO 8      32-bit-string index 9
   bit 7 =  GPIO 7      32-bit-string index 8
   bit 8 =  GPIO 12     32-bit-string index 13
   bit 9 =  GPIO 16     32-bit-string index 17
   bit 10 = GPIO 20     32-bit-string index 21
   bit 11 = GPIO 21     32-bit-string index 22
   bit 12 = GPIO 26     32-bit-string index 27
   bit 13 = GPIO 19     32-bit-string index 20
   bit 14 = GPIO 13     32-bit-string index 14
   bit 15 = GPIO 6      32-bit-string index 7
   */

   INP_GPIO(6); 
   INP_GPIO(7);
   INP_GPIO(8);
   INP_GPIO(12);
   INP_GPIO(13);
   INP_GPIO(14);
   INP_GPIO(15);
   INP_GPIO(16);
   INP_GPIO(18);
   INP_GPIO(19);
   INP_GPIO(20);
   INP_GPIO(21);
   INP_GPIO(23);
   INP_GPIO(24);
   INP_GPIO(25);
   INP_GPIO(26);
    
   INP_GPIO(17);
   INP_GPIO(3); // Define GPIO 3 as input for BUSY pin from ADC 
	INP_GPIO(4); // Define GPIO 4 as input before next step 
   OUT_GPIO(17); // Redefine GPIO 17 as output RD 
	OUT_GPIO(4);  // Redefine GPIO 4 as output CONVST
  
   int CONVST = 4; 
   int BUSY = 3;
   int RD = 17;

   GPIO_SET = 1 << RD;        // set RD HIGH 
   GPIO_SET = 1 << CONVST;    // set CONVST HIGH 


   int nbr_of_samples = 1700000; 
   int data_array[1700000] = {}; 
   int counter = 0; 
   // Disable IRQ  
   // Local_irq_disable()  <-- This would need to be done with a sepparate kernel module  
   // Local_fiq_disable()  <-- This would need to be done with a sepparate kernel module 

	while(counter < nbr_of_samples)
	 {
      GPIO_CLR = 1 << CONVST; 	// Reset CONVST to LOW - initiate adc conversion
      GPIO_CLR = 1 << RD;        // Bring synchronization pin RD low to make parallel data out available 

      while(GPIO_READ_PIN(3) == 1){ 
        // printf("entered BUSY loop");
        // while the BUSY pin is high wait for ADC to finish conversion and change apears on BUSY pin
        //BUSY_state = GPIO_READ_PIN(3);
      }

      data_array[counter] = GPIO_READ; // read the whole 32-bit GPIO register (includes ADC output)
      //sleep(0.001);
      GPIO_SET = 1 << RD;        // Bring RD pin HIGH again 
      GPIO_SET = 1 << CONVST;   // Bring CONVST pin high again 
      
      counter++;
    }

   //Enable IRQ
   //local_fiq_enable(); <-- Needs to be done with a sepparate kernel module 
   //local_irq_enable(); <-- Needs to be done with a sepparate kernel module 

   for (int i = 0; i < nbr_of_samples; i++) // print the data array out 
   {
      printf("%i", data_array[i]); 
      if(i < nbr_of_samples - 1) // in order to NOT print a comma after last value 
      {
         printf(","); 
      }
   }

    
	return 0; 




}
